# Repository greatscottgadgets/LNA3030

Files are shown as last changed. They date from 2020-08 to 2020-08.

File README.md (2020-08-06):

# LNA3030

LNA3030 is an in-line SMA Low Noise Amplifier with SAW filter.

## hardware notes

Schematic and layout files were designed in KiCad, an open source electronic
design automation package.

This design may be assembled with any SAW filter with a standard 3.0 x 3.0 mm
footprint (DCC6C).

The PCB is designed to fit the Crystek SMA-KIT-1.5MF housing.

```
order of copper layers:
    Copper 1:  F (front)
    Copper 2:  In1
    Copper 3:  In2
    Copper 4:  B (back)

PCB description: 4 layer PCB 0.8 mm
    Copper       1:  0.035 mm (1 oz)
    Dielectric 1-2:  0.2 mm prepreg
    Copper       2:  0.0175 mm (0.5 oz)
    Dielectric 2-3:  0.265 mm core
    Copper       3:  0.0175 mm (0.5 oz)
    Dielectric 3-4:  0.2 mm prepreg
    Copper       4:  0.035 mm (1 oz)

7628 prepreg with Er=4.6
double side solder mask green
double side silkscreen white
7 mil minimum trace width
5 mil minimum isolation
```

PCBs of this specification are available from JLCPCB (JLC7628 4-layer 0.8 mm stackup).

## frequency options

LNA3030 may be populated with different components to support various frequency
bands.

frequency band | U4 part number       | L1-L4 part number | C1-C6 part number
---------------|----------------------|-------------------|-------------------
314-315 MHz    | B39321B3722U410      | HK1005R27J-T      | GCM1555C1H681JA16D
430-435 MHz    | B39431B3710U410      | HK1005R27J-T      | GCM155R71H471KA37D
868-870 MHz    | SF2415E              | HK1005R10J-T      | GCM1555C1H470JA16D

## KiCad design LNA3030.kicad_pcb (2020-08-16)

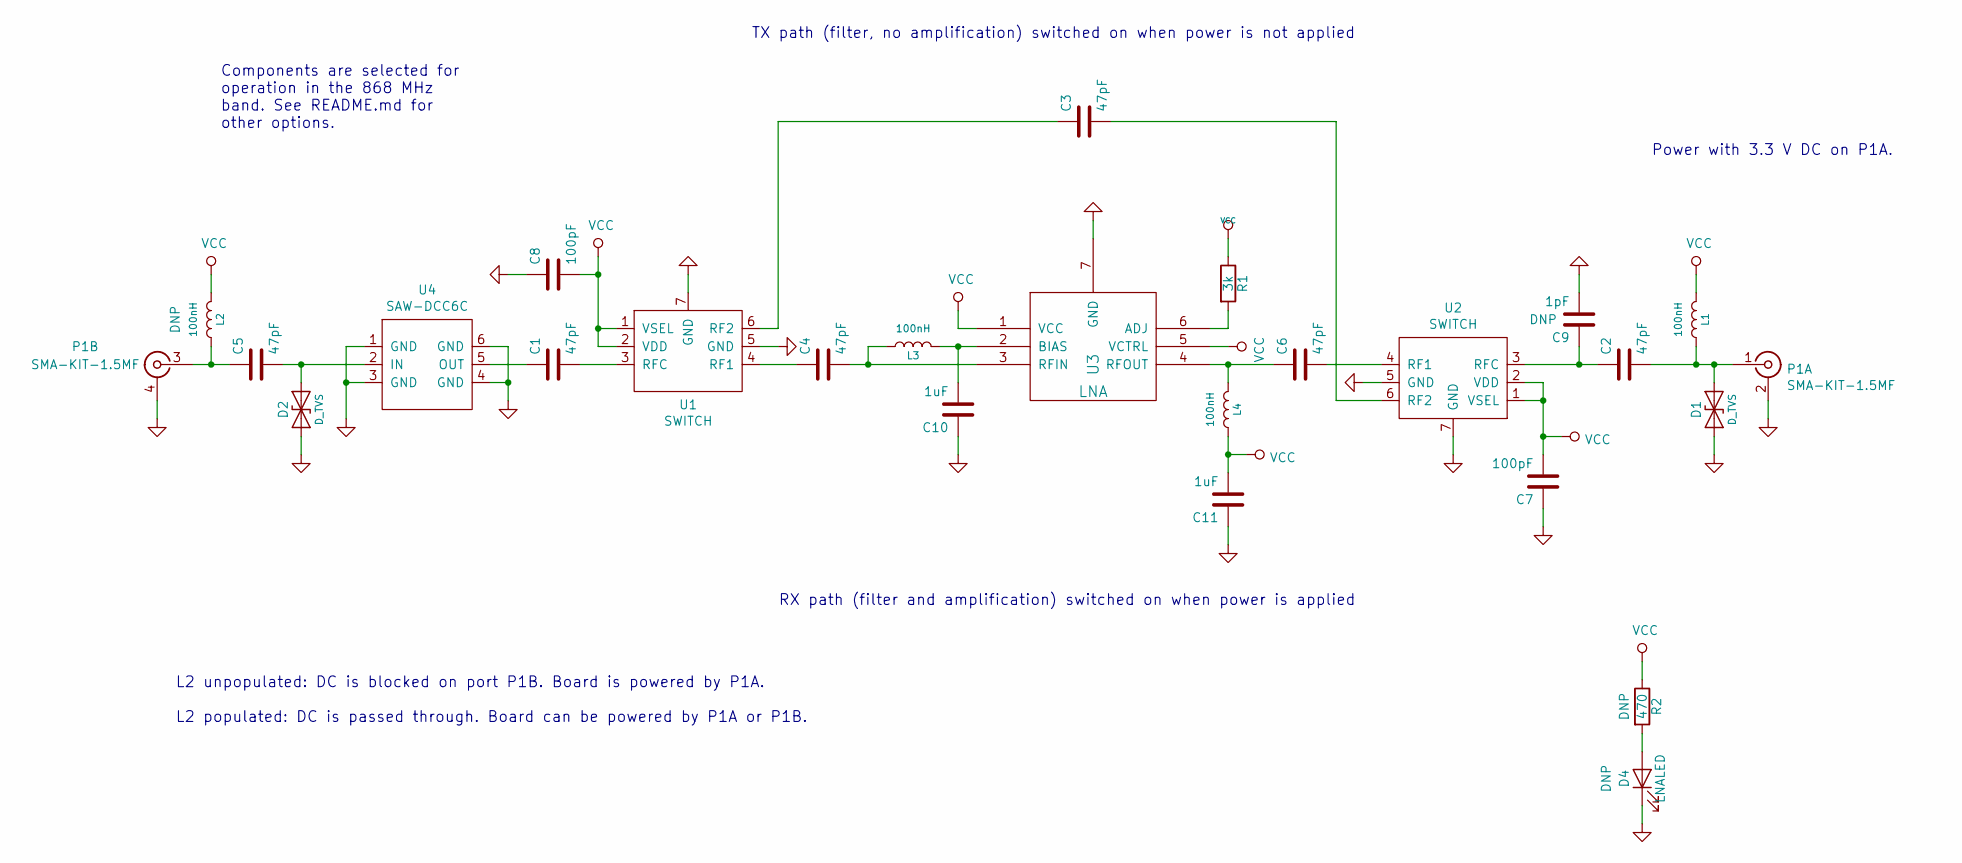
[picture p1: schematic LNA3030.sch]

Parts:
C1, C2, C3, C4, C5, C6: 47pF; 0402; Part Number GCM1555C1H470JA16D
C7, C8: 100pF; 0402; Part Number GCM1555C1H101JA16D
C9: 1pF; 0402
C10, C11: 1uF; 0402; Part Number LMK105BJ105KV-F
D1, D2: D_TVS; 0402; Part Number LXES15AAA1-153
D4: LNALED; 0402
L1, L2, L3, L4: 100nH; 0402; Part Number HK1005R10J-T
P1: SMA-KIT-1.5MF; Part Number SMA-KIT-1.5MF
R1: 3k; 0402; Part Number RMCF0402FT3K00
R2: 470; 0402; Part Number RMCF0402JT470R
U1, U2: SWITCH; GRF6011; Part Number GRF6011
U3: LNA; TSLP-7-1; Part Number BGB 741L7ESD E6327
U4: SAW-DCC6C; DCC6C; Part Number SF2415E

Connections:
GND: C7.1, C8.1, C9.2, C10.1, C11.1, D1.1 (A1), D2.1 (A1), D4.1 (K), P1.2 (SHIELD), P1.4 (SHIELD), U1.5 (GND), U1.7 (GND), U2.5 (GND), U2.7 (GND), U3.7 (GND), U4.1 (GND), U4.3 (GND), U4.4 (GND), U4.6 (GND)
unnamed: C1.1, U4.5 (OUT)
unnamed: C1.2, U1.3 (RFC)
unnamed: C2.1, C9.1, U2.3 (RFC)
unnamed: C2.2, D1.2 (A2), L1.1, P1.1 (RF)
unnamed: C3.1, U1.6 (RF2)
unnamed: C3.2, U2.6 (RF2)
unnamed: C4.1, U1.4 (RF1)
unnamed: C4.2, L3.1, U3.3 (RFIN)
unnamed: C5.1, L2.1, P1.3 (RF)
unnamed: C5.2, D2.2 (A2), U4.2 (IN)
unnamed: C6.1, L4.2, U3.4 (RFOUT)
unnamed: C6.2, U2.4 (RF1)
unnamed: C10.2, L3.2, U3.2 (BIAS)
unnamed: D4.2 (A), R2.2
unnamed: R1.2, U3.6 (ADJ)
VCC: C7.2, C8.2, C11.2, L1.2, L2.2, L4.1, R1.1, R2.1, U1.1 (VSEL), U1.2 (VDD), U2.1 (VSEL), U2.2 (VDD), U3.1 (VCC), U3.5 (VCTRL)

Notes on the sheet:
TX path (filter, no amplification) switched on when power is not applied
RX path (filter and amplification) switched on when power is applied
L2 unpopulated: DC is blocked on port P1B. Board is powered by P1A. L2 populated: DC is passed through. Board can be powered by P1A or P1B.
Components are selected for operation in the 868 MHz band. See README.md for other options.
Power with 3.3 V DC on P1A.

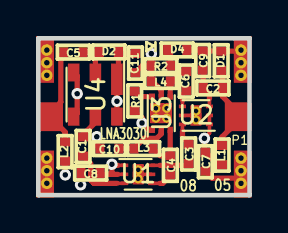
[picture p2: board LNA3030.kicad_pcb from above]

Board: 4 copper layers, 11.7 x 8.7 mm, 25 parts (0 on the bottom side), 17 nets.

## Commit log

2020-08-05 initial commit, copied from LNA1109
    [LNA3030.kicad_pcb, LNA3030.sch]
2020-08-06 modify for DCC6C SAW filters
    [LNA3030.kicad_pcb, LNA3030.sch]
2020-08-06 correct C7 and C8 part selection
    [LNA3030.kicad_pcb, LNA3030.sch]
2020-08-16 disable gerber advanced attributes
    [LNA3030.kicad_pcb]

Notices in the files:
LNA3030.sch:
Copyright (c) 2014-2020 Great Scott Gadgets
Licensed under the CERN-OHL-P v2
